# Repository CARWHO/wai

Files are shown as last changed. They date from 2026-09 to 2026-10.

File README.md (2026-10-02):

# Wai

The health monitor for your farm. It does the checking for you.

2nd at the [OpenAI Hackathon](https://saasathon.dev). Mobile app, web app and the hardware, all demoed live. [trywai.now](https://trywai.now)

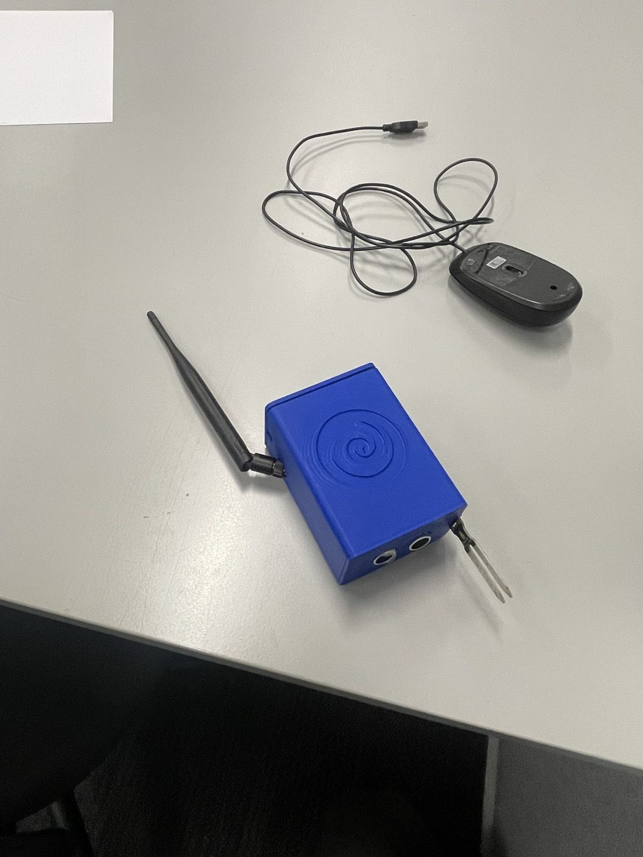
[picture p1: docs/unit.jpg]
Wai sensor unit


## Problem

- 2 h a day driving round the farm to check water and soil.
- +43% on fertiliser costs.
- $1M fine for run-off from fertilising before the rain.

## How it works

Probe → LoRa (no SIM) → gateway → cloud → AI.

Every reading lands live. The AI works out the cause, the fix and how long you've got.

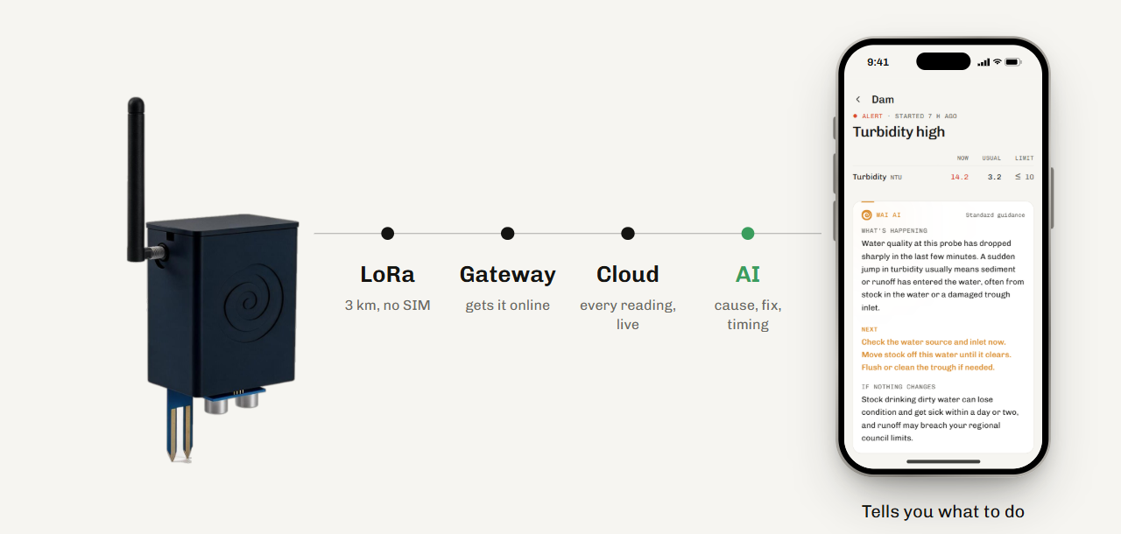
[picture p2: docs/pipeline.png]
Probe, LoRa, gateway, cloud, AI, app


## App

<p>
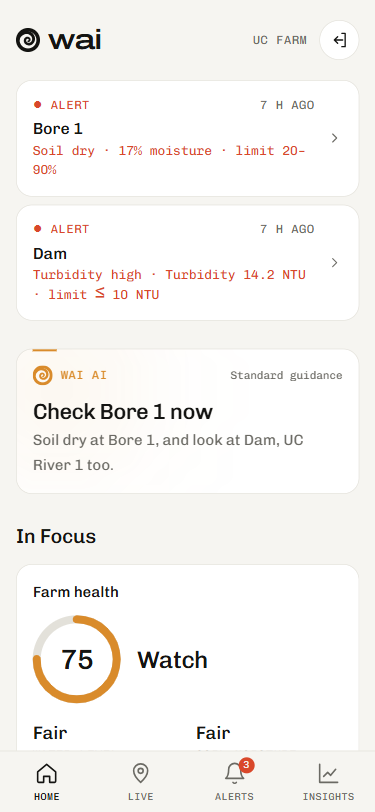
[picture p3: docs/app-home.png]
Home: alerts, Wai AI guidance and farm health score
  
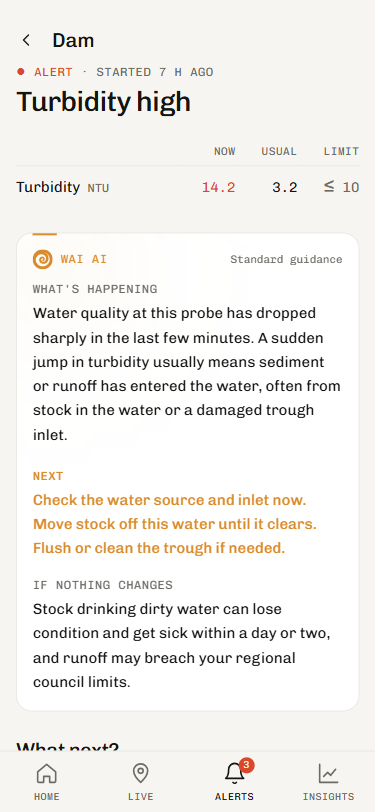
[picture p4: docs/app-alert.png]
Alert: what's happening, what to do next, what happens if nothing changes
  
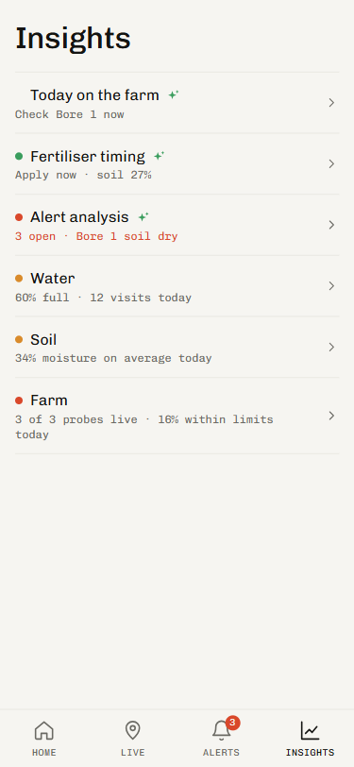
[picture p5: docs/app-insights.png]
Insights: fertiliser timing, water, soil and farm summary
  
</p>

- Farm health score
- Wai AI: suggestions and insights on each probe's current readings
- Alerts: what changed, why, what to do, what it costs if you wait
- Map of probes, with health and battery
- Live readings from the real hardware

The app is SwiftUI on Supabase. The original Next.js web app is in the git history before the `swift-primary` branch.

## Code

| Path | Contents |
|---|---|
| `Sources/WaiKit` | `Models`, `Metrics`, `Derive`, `Demo`, `Farm` (domain), `FarmStore`, `SessionStore`, `Location`, `CommandsStore`, `AIClient` |
| `Sources/WaiUI` | `Theme`, `Fonts` (Chivo, Chivo Mono, Archivo, bundled), `Components/`, `Screens/`, `Router`, `RootView` |
| `Sources/WaiiOS` | `@main` for the iOS app (Xcode project generated from `project.yml`) |
| `Sources/WaiMac` | `@main` for the macOS dev runner |
| `Sources/WaiKitCheck` | fixture checks against `Fixtures/` |
| `Sources/WaiLiveCheck` | live Supabase smoke check |
| `api/ai.ts` | Vercel function for the AI text (`https://wai-olive.vercel.app/api/ai`). The app calls it. |
| `hardware/` | firmware, wiring and enclosure |

### Open in Xcode

```sh
xcodegen generate     # only after editing project.yml; Wai.xcodeproj is committed
open Wai.xcodeproj    # scheme Wai, run on a simulator or a phone
```

Set your team under Signing before running on a phone. Location permission text is in `project.yml`.

### Without Xcode (Command Line Tools only)

```sh
swift build                          # every target, macOS
swift run WaiKitCheck                # domain checks against Fixtures/
swift run WaiLiveCheck               # loads the real farm from Supabase and prints the scores
WAI_SKIP_LOGIN=1 swift run WaiMac    # the app in a 390×844 macOS window, anonymous reads
swift run WaiMac                     # with the login screen
```

Command Line Tools ship neither XCTest nor swift-testing, so `WaiKitCheck` is an executable that exits 1 on any failure.
The fixtures were generated from the TypeScript domain code before it was retired. They are the frozen reference.

### AI function

`api/ai.ts` runs on Vercel with `OPENAI_API_KEY` (and optional `OPENAI_MODEL`) set in the project. Without a key it answers
with the rule-based fallback. Deploy with `vercel deploy` from the repo root. `vercel.json` sets no framework.

## Pricing

$99/month for the software, per device. Hardware is $0 upfront.

## Hardware

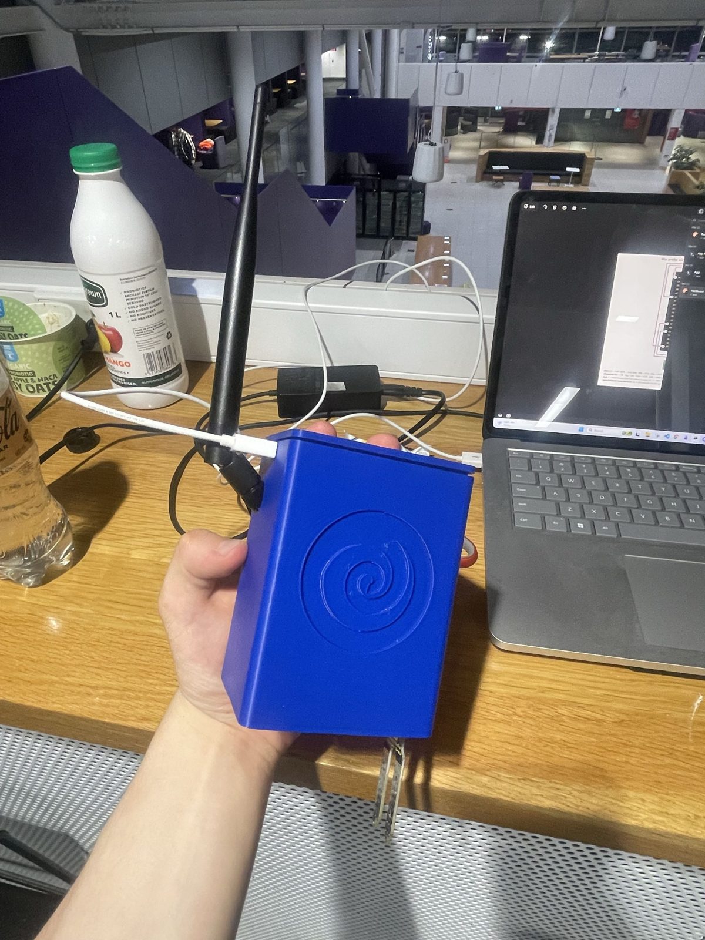
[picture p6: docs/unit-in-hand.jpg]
Holding the unit at the hackathon


Probes chain over LoRa. Each one reaches 1 to 3 km to the next, so a string of them covers a whole farm with one gateway.

- ESP32
- LoRa radio, 923 MHz
- GPS
- Ultrasonic water level sensor
- Soil moisture probe
- 3D printed case

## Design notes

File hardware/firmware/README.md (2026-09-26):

# Wai probe firmware

ESP32 (Jaycar XC3800) reads the trough water level and posts it to Supabase `readings` every 5 s. The app updates live through Realtime.

## Setup

1. Install [PlatformIO](https://platformio.org/install/cli) (`pip install platformio`) or the VS Code extension.
2. `cp include/secrets.example.h include/secrets.h` and fill in Wi-Fi, Supabase URL, publishable key and the probe id.
3. Plug the ESP32 in over USB, then `pio run -t upload && pio device monitor`.

## Modes

`SIMULATE` in `include/config.h`:

- `1`: no sensors needed. Sends a fake level that drains from 25 cm to 5 cm and refills.
- `0`: reads the real HC-SR04. Set `TANK_DEPTH_CM` to the distance from the sensor to the trough floor.

## Wiring

| Part | Pin | ESP32 |
|---|---|---|
| HC-SR04 | VCC | V5 |
| | Trig | GPIO 5 |
| | Echo | GPIO 18, through 1k/1.8k divider (1k Echo→GPIO 18, 1.8k GPIO 18→GND) |
| | GND | GND |
| Soil sensor | + | 3V3 |
| | S | GPIO 34 |
| | − | GND |
| GPS (XC3710, optional) | VCC | 3V3 |
| | GND | GND |
| | TX | GPIO 16 |
| | RX | GPIO 17 |

## Data

Each row sets `level_cm` (the only value the app uses today) and puts everything the probe read, unprocessed, into the `raw` jsonb column:

- Ultrasonic: `echo_us` (5 raw pulse widths), `echo_ok`, `distance_cm` (median)
- Soil: `soil_adc`, `soil_mv`, `soil_pct`
- Board: `uptime_s`, `rssi`, `wifi_ch`, `mac`, `free_heap`, `chip_temp_c` (die, not air), `fw`
- GPS, once a module sends valid data: `gps.{sats, fix, lat, lng, hdop, alt_m, speed_kmh, utc, age_ms, chars}`

Turn these into data points (litres, use per day, time to empty, ...) later, on the app side.

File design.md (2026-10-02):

# Design

> Superseded. This is the hackathon design note for the Next.js web app, which the `swift-primary` branch retired. The app is now the SwiftUI package at the repo root; see `README.md`. The Supabase backend, hardware and AI prompts are unchanged.

## Stack

| Layer | Choice |
|---|---|
| App | Next.js + Tailwind, installable PWA. Same tokens and fonts as the landing page (wai-web) |
| Hosting | Vercel (auto-deploy on push) |
| Backend | Supabase: Postgres, auth, Realtime |
| Hardware | ESP32 + sensors → Supabase REST over Wi-Fi |
| AI | OpenAI API via Next.js API routes |
| Emulation | Real iPhone (PWA on home screen) mirrored to Windows laptop via AeroMirror (AirPlay). Backup: Chrome DevTools device mode |
| Later | SwiftUI port on Mac, same Supabase backend |

## Libraries

| Need | Library |
|---|---|
| Framework | `next` (React 19) |
| UI | Own components in `src/components/ui.tsx`, styled with the landing page tokens (paper, ink, muted, line, healthy, alert) |
| Styling | Tailwind v4; Geist for text, JetBrains Mono for labels, units and readings |
| Backend / live data | `@supabase/supabase-js` |
| AI | `openai` (API route) |
| Map | `react-leaflet` + Esri satellite tiles (free, no key) |
| Charts | `recharts` |
| PWA | Next built-in `app/manifest.ts` |

## Data flow

ESP32 → Supabase (insert reading) → Realtime → app updates live → API route calls OpenAI → diagnosis / prediction / suggestion

## Inspiration

**Farm**
- [Halter](https://apps.apple.com/nz/app/halter/id1453448841): collars + app; virtual fences, AI health alerts
- [Farmbot](https://farmbot.com.au/): tank, bore, dam, rain monitoring; 10k+ AU producers
- [Farmdeck](https://www.farmdeck.com/features/water-level-monitoring/): real-time water levels
- [Intelli-Tank](https://apps.apple.com/us/app/intelli-tank/id1381515840): tank level + temperature app
- [Aqvify](https://aqvify.com/): well and tank level app

**Fitness (health score pattern)**
- [Oura Readiness Score](https://support.ouraring.com/hc/en-us/articles/360025589793-Readiness-Score): one 0–100 score from many signals
- [WHOOP vs Oura vs Garmin scores](https://www.kygo.app/post/recovery-scores-compared-whoop-oura-garmin): how recovery scores are built

## Demo

- **Primary**: real iPhone, app added to home screen, mirrored to Windows laptop via AeroMirror (AirPlay). Bad Wi-Fi → USB + Personal Hotspot.
- **Backup**: Chrome DevTools device mode (iPhone frame).
- **Last resort**: recorded video.

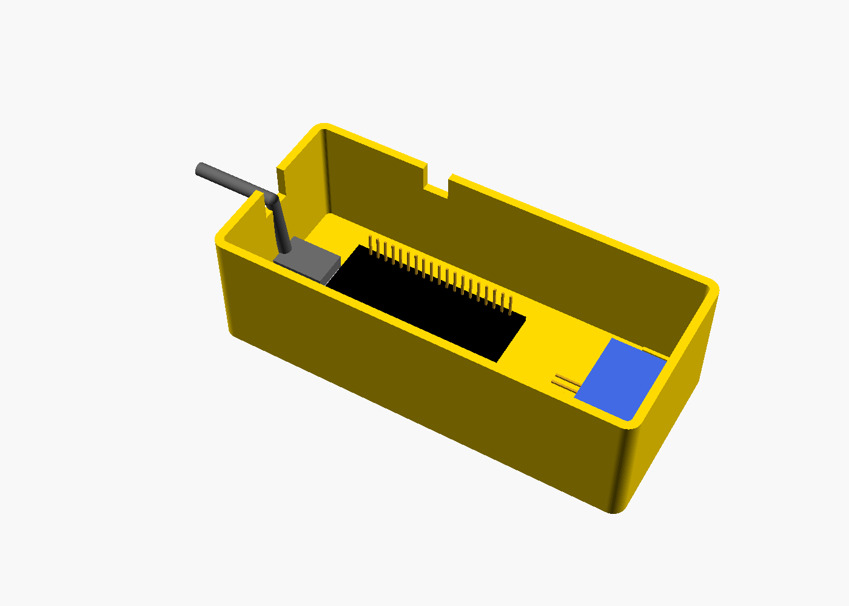
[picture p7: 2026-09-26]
hardware/enclosure/renders/inside.png

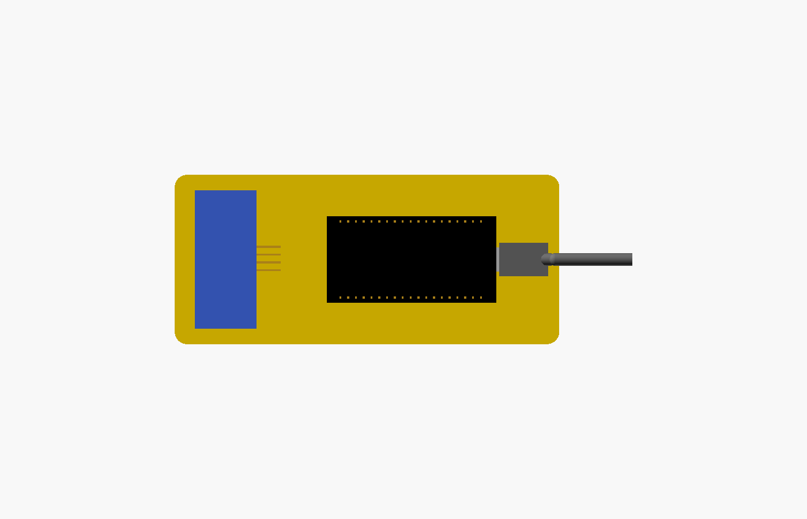
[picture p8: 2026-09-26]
hardware/enclosure/renders/top.png

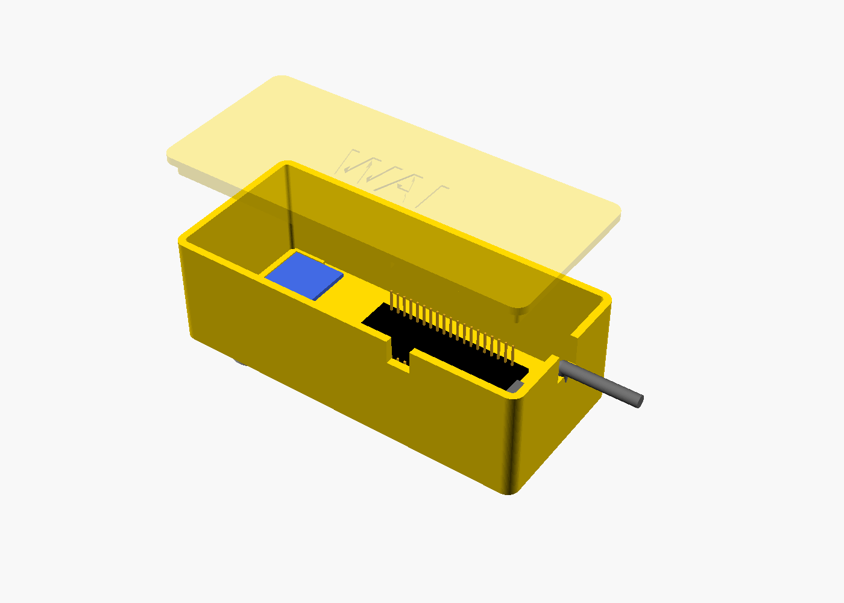
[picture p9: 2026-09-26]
hardware/enclosure/renders/with_lid.png

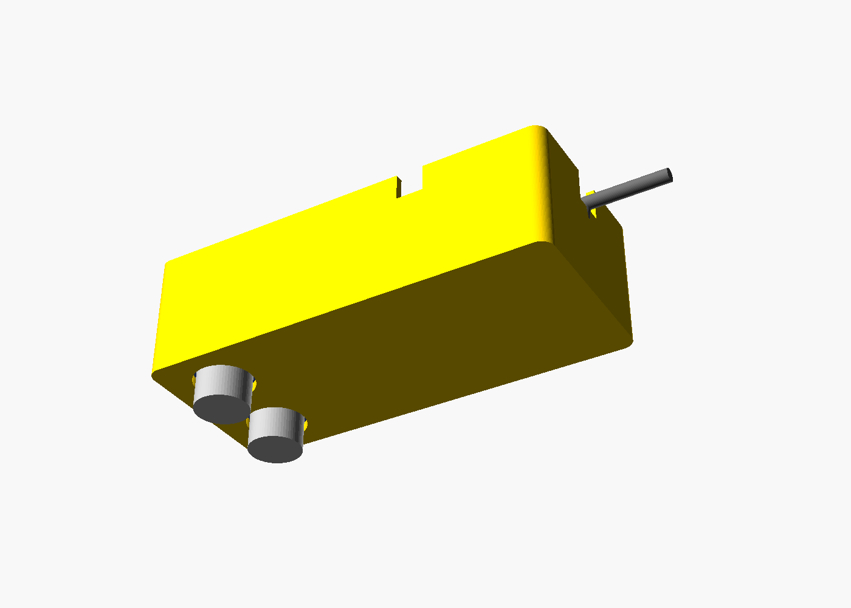
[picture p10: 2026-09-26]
hardware/enclosure/renders/underside.png

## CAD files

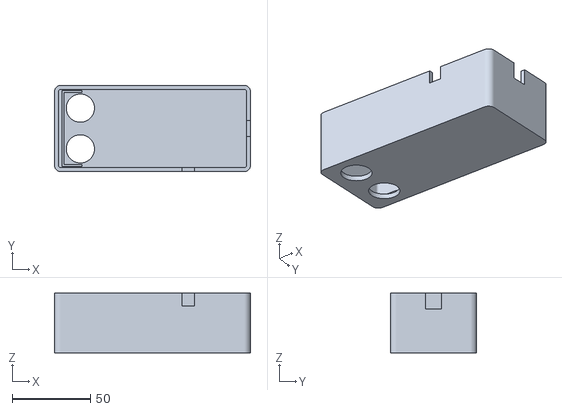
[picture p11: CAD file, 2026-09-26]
hardware/enclosure/wai_base.stl
125.0 x 55.0 x 38.0

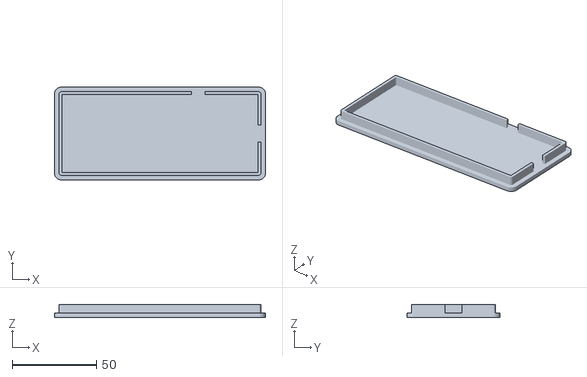
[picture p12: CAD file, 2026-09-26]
hardware/enclosure/wai_lid.stl
125.0 x 55.0 x 7.50

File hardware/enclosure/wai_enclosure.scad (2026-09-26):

// Wai demo enclosure
// Parts: ESP32 core board (Jaycar XC3800), HC-SR04 (Jaycar XC4442), optional soil sensor wires (XC4604).
// Power: USB cable from a laptop. No battery inside.
// HC-SR04 sits on the floor with its transducers pointing down through two holes, over the water.
// ESP32 is taped upside down (pins up) by its metal RF shield with double-sided tape,
// USB end facing the cable notch. The pins stick out underneath, so it can't sit flat pins-down.
// All sizes in mm. Measure your parts and adjust the variables below before printing.

part = "assembly"; // "base", "lid", "assembly", "print", "demo" (with mock parts)

/* [Interior] */
in_l = 120;  // interior length (X): HC-SR04 + its jumpers + ESP32 + micro-USB plug
in_w = 50;   // interior width (Y)
in_h = 35;   // interior height, floor top to rim

/* [Shell] */
wall  = 2.5;
floor_t = 3;
corner_r = 4;

/* [HC-SR04] */
hc_pcb_l = 45;        // PCB length (along Y)
hc_pcb_w = 20;        // PCB width (along X)
hc_tx_pitch = 26;     // centre-to-centre of the two transducers
hc_hole_d = 18;       // transducers are ~16 mm; 1 mm clearance each side
hc_rail_h = 1.5;      // low locating rails around the PCB
hc_clear = 0.5;
hc_x = 4;             // gap from the end wall to the PCB

/* [Cable exits] */
usb_notch_w = 10;     // USB cable exit, notch from the rim (micro-USB plug stays inside)
usb_notch_d = 10;
soil_notch_w = 8;     // soil sensor wires
soil_notch_d = 8;

/* [Lid] */
lid_t = 2.5;
lip_h = 5;
lip_t = 1.6;
lid_clear = 0.25;     // per side; friction fit for PLA
label = "WAI";
label_size = 14;
label_depth = 0.6;

$fn = 64;

out_l = in_l + 2 * wall;
out_w = in_w + 2 * wall;
out_h = in_h + floor_t;

module rounded_box(l, w, h, r) {
    translate([r, r, 0])
        linear_extrude(h)
            offset(r = r) square([l - 2 * r, w - 2 * r]);
}

module base() {
    difference() {
        rounded_box(out_l, out_w, out_h, corner_r);
        // cavity
        translate([wall, wall, floor_t])
            rounded_box(in_l, in_w, in_h + 1, max(corner_r - wall, 0.5));

        // HC-SR04 transducer holes, centred across the width
        hc_cx = wall + hc_x + hc_pcb_w / 2;
        for (dy = [-hc_tx_pitch / 2, hc_tx_pitch / 2])
            translate([hc_cx, out_w / 2 + dy, -1])
                cylinder(d = hc_hole_d, h = floor_t + 2);

        // USB notch in the far end wall
        translate([out_l - wall - 1, out_w / 2 - usb_notch_w / 2, out_h - usb_notch_d])
            cube([wall + 2, usb_notch_w, usb_notch_d + 1]);

        // soil sensor notch in a long wall
        translate([out_l * 0.65, -1, out_h - soil_notch_d])
            cube([soil_notch_w, wall + 2, soil_notch_d + 1]);
    }

    // locating rails for the HC-SR04 PCB; open on the pin side (+X)
    rx = wall + hc_x - hc_clear;
    ry = out_w / 2 - hc_pcb_l / 2 - hc_clear;
    rl = hc_pcb_w + 2 * hc_clear;
    rw = hc_pcb_l + 2 * hc_clear;
    translate([0, 0, floor_t]) {
        translate([rx - 1.2, ry - 1.2, 0]) cube([1.2, rw + 2.4, hc_rail_h]);
        translate([rx - 1.2, ry - 1.2, 0]) cube([rl * 0.6, 1.2, hc_rail_h]);
        translate([rx - 1.2, ry + rw, 0]) cube([rl * 0.6, 1.2, hc_rail_h]);
    }
}

module lid() {
    difference() {
        union() {
            rounded_box(out_l, out_w, lid_t, corner_r);
            // lip that drops inside the base walls
            c = lid_clear;
            ir = max(corner_r - wall - c, 0.5);
            translate([wall + c, wall + c, -lip_h])
                difference() {
                    rounded_box(in_l - 2 * c, in_w - 2 * c, lip_h, ir);
                    translate([lip_t, lip_t, -1])
                        rounded_box(in_l - 2 * c - 2 * lip_t, in_w - 2 * c - 2 * lip_t,
                                    lip_h + 2, max(ir - lip_t, 0.5));
                }
        }
        // engraved label on the top face
        translate([out_l / 2, out_w / 2, lid_t - label_depth])
            linear_extrude(label_depth + 1)
                text(label, size = label_size, halign = "center", valign = "center",
                     font = "Liberation Sans:style=Bold");
        // cut the lip where the cable notches are so the lid seats over the cables
        translate([out_l - wall - lip_t - 2, out_w / 2 - usb_notch_w / 2, -lip_h - 1])
            cube([lip_t + 4, usb_notch_w, lip_h + 1]);
        translate([out_l * 0.65, wall - 1, -lip_h - 1])
            cube([soil_notch_w, lip_t + 3, lip_h + 1]);
    }
}

// Approximate parts, only for the "demo" render. Not printed.
demo_lid = true;
esp_l = 55; esp_w = 28; esp_pcb = 1.6; esp_shield = 3.2; tape_t = 1;
module mock_parts() {
    hc_x0 = wall + hc_x;
    hc_y0 = out_w / 2 - hc_pcb_l / 2;
    // HC-SR04: PCB on the floor, transducers down through the holes, pins toward +X
    translate([hc_x0, hc_y0, floor_t]) {
        color("royalblue") cube([hc_pcb_w, hc_pcb_l, esp_pcb]);
        for (dy = [-hc_tx_pitch / 2, hc_tx_pitch / 2])
            color("silver") translate([hc_pcb_w / 2, hc_pcb_l / 2 + dy, -floor_t - 9])
                cylinder(d = 16, h = floor_t + 9);
        for (i = [0:3])
            color("goldenrod") translate([hc_pcb_w, hc_pcb_l / 2 - 3.8 + i * 2.54, 0.5])
                cube([8, 0.64, 0.64]);
    }
    // ESP32 upside down: tape, RF shield, PCB, pins up. USB end at +X.
    ex0 = out_l - wall - 18 - esp_l;   // leave ~18 mm for the micro-USB plug
    ey0 = out_w / 2 - esp_w / 2;
    translate([ex0, ey0, floor_t]) {
        color("white") translate([2, 4, 0]) cube([18, 20, tape_t]);
        color("lightgray") translate([2, 5, tape_t]) cube([18, 18, esp_shield]);
        translate([0, 0, tape_t + esp_shield]) {
            color("black") cube([esp_l, esp_w, esp_pcb]);
            for (y = [1.3, esp_w - 1.3 - 0.64])
                for (i = [0:18])
                    color("goldenrod") translate([4 + i * 2.54, y, esp_pcb]) cube([0.64, 0.64, 8]);
            color("silver") translate([esp_l - 5, esp_w / 2 - 4, -3]) cube([6, 8, 3]); // micro-USB port
        }
        // micro-USB plug and cable out through the notch
        color("dimgray") translate([esp_l + 1, esp_w / 2 - 5.5, tape_t + esp_shield - 3]) cube([16, 11, 7]);
    }
    color("dimgray")
        hull() {
            translate([out_l - wall - 2, out_w / 2, floor_t + tape_t + esp_shield]) sphere(d = 4);
            translate([out_l - wall / 2, out_w / 2, out_h - usb_notch_d + 2]) sphere(d = 4);
        }
    color("dimgray") translate([out_l - wall / 2, out_w / 2, out_h - usb_notch_d + 2])
        rotate([0, 90, 0]) cylinder(d = 4, h = 25);
}

if (part == "base") base();
else if (part == "lid") translate([0, out_w, lid_t]) rotate([180, 0, 0]) lid();
else if (part == "print") {
    base();
    translate([0, 2 * out_w + 10, lid_t]) rotate([180, 0, 0]) lid();
}
else if (part == "demo") { // mock parts for a visual check, lid lifted
    color("gold") base();
    if (demo_lid) color("gold", 0.35) translate([0, 0, out_h + 30]) lid();
    mock_parts();
}
else { // assembly, lid lifted to show the inside
    base();
    translate([0, 0, out_h + 20]) lid();
}

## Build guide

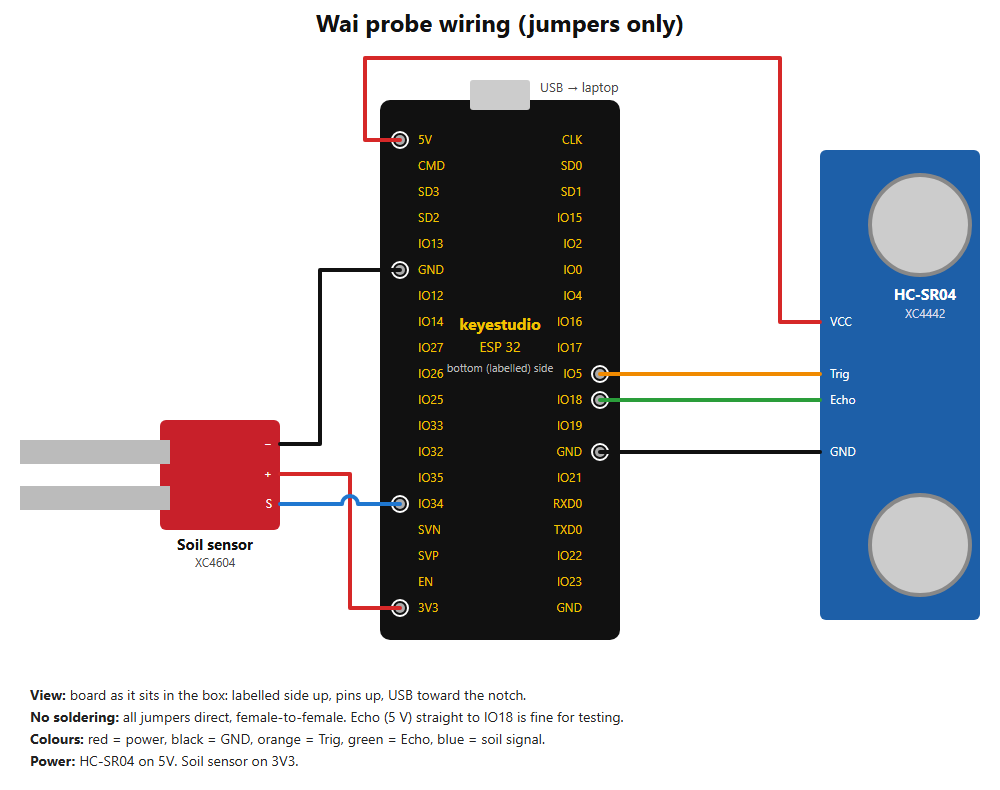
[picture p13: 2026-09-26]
hardware/wiring.png

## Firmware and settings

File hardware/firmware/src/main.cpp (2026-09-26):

// Wai probe: reads every sensor it has and inserts a row into Supabase `readings` over Wi-Fi
// every few seconds. level_cm is the one processed value the app uses today; everything else
// goes unprocessed into the `raw` jsonb column, to be turned into data points later.
// The app picks new rows up through Supabase Realtime.

#include <Arduino.h>
#include <WiFi.h>
#include <WiFiClientSecure.h>
#include <HTTPClient.h>
#include <ArduinoJson.h>
#include <TinyGPSPlus.h>
#include <algorithm>

#include "config.h"
#if __has_include("secrets.h")
#include "secrets.h"
#else
#error "Copy include/secrets.example.h to include/secrets.h and fill it in"
#endif

static TinyGPSPlus gps;

static void connectWifi() {
  if (WiFi.status() == WL_CONNECTED) return;
  Serial.printf("Wi-Fi: connecting to %s", WIFI_SSID);
  WiFi.mode(WIFI_STA);
  WiFi.begin(WIFI_SSID, WIFI_PASSWORD);
  for (int i = 0; i < 20 && WiFi.status() != WL_CONNECTED; i++) {
    delay(250);
    Serial.print('.');
  }
  if (WiFi.status() == WL_CONNECTED)
    Serial.printf(" ok, %s, RSSI %d dBm\n", WiFi.localIP().toString().c_str(), WiFi.RSSI());
  else
    Serial.println(" failed, retrying next loop");
}

// ---- HC-SR04 ----

// One ping: echo pulse width in us, 0 if no echo within ~5 m.
static unsigned long pingUs() {
  digitalWrite(PIN_TRIG, LOW);
  delayMicroseconds(2);
  digitalWrite(PIN_TRIG, HIGH);
  delayMicroseconds(20); // 10 us is the spec minimum; this board needs longer
  digitalWrite(PIN_TRIG, LOW);
  return pulseIn(PIN_ECHO, HIGH, 30000);
}

// 5 pings. Raw widths go in `raw`; the median distance (cm) is returned, NAN if none echoed.
static float readUltrasonic(JsonObject raw) {
  JsonArray pings = raw["echo_us"].to<JsonArray>();
  float v[5];
  int n = 0;
  for (int i = 0; i < 5; i++) {
    unsigned long us = pingUs();
    pings.add(us);
    if (us) v[n++] = us / 58.0f;
    delay(60); // let echoes die down
  }
  raw["echo_ok"] = n;
  if (!n) return NAN;
  std::sort(v, v + n);
  float d = v[n / 2]; // median ignores the HC-SR04's outliers
  raw["distance_cm"] = roundf(d * 10) / 10;
  return d;
}

// ---- Soil ----

static void readSoil(JsonObject raw) {
  int adc = analogRead(PIN_SOIL);
  raw["soil_adc"] = adc;
  raw["soil_mv"] = analogReadMilliVolts(PIN_SOIL);
  raw["soil_pct"] = constrain(map(adc, SOIL_DRY, SOIL_WET, 0, 100), 0, 100);
}

// ---- Board ----

static void readBoard(JsonObject raw) {
  raw["uptime_s"] = millis() / 1000;
  raw["rssi"] = WiFi.RSSI();
  raw["wifi_ch"] = WiFi.channel();
  raw["mac"] = WiFi.macAddress();
  raw["free_heap"] = ESP.getFreeHeap();
  raw["chip_temp_c"] = roundf(temperatureRead() * 10) / 10; // die temperature, not air
  raw["fw"] = FW_VERSION;
}

// ---- GPS (XC3710, optional) ----

// NMEA arrives continuously; feed the parser from loop() so no sentences are dropped.
static void feedGps() {
  while (Serial2.available()) gps.encode(Serial2.read());
}

// Adds GPS fields only once a module has sent a valid sentence (a floating RX pin reads noise),
// so rows without GPS stay clean.
static void readGps(JsonObject raw) {
  if (!gps.passedChecksum()) return;
  JsonObject g = raw["gps"].to<JsonObject>();
  g["chars"] = gps.charsProcessed();
  g["sats"] = gps.satellites.isValid() ? (int)gps.satellites.value() : 0;
  g["fix"] = gps.location.isValid() && gps.location.age() < 5000;
  if (gps.location.isValid()) {
    g["lat"] = serialized(String(gps.location.lat(), 6));
    g["lng"] = serialized(String(gps.location.lng(), 6));
    g["age_ms"] = gps.location.age();
  }
  if (gps.hdop.isValid()) g["hdop"] = gps.hdop.hdop();
  if (gps.altitude.isValid()) g["alt_m"] = gps.altitude.meters();
  if (gps.speed.isValid()) g["speed_kmh"] = gps.speed.kmph();
  if (gps.date.isValid() && gps.time.isValid()) {
    char utc[21];
    snprintf(utc, sizeof utc, "%04d-%02d-%02dT%02d:%02d:%02dZ", gps.date.year(), gps.date.month(),
             gps.date.day(), gps.time.hour(), gps.time.minute(), gps.time.second());
    g["utc"] = utc;
  }
}

// ---- Level (the one processed value the app uses) ----

static float levelCm(float distance) {
#if SIMULATE
  // Drains 1 cm per reading from 25 cm to 5 cm, then refills. Low level shows up as an alert.
  static float level = 25;
  level -= 1;
  if (level < 5) level = 25;
  return level + random(-20, 21) / 100.0f;
#else
  if (isnan(distance)) return NAN;
  return constrain(TANK_DEPTH_CM - distance, 0.0f, TANK_DEPTH_CM);
#endif
}

static bool send(JsonDocument &doc) {
  WiFiClientSecure tls;
  tls.setInsecure(); // demo only: skips certificate checks
  HTTPClient http;
  http.begin(tls, String(SUPABASE_URL) + "/rest/v1/readings");
  http.addHeader("apikey", SUPABASE_KEY);
  http.addHeader("Content-Type", "application/json");
  http.addHeader("Prefer", "return=minimal");

  String body;
  serializeJson(doc, body);
  int code = http.POST(body);
  if (code != 201) Serial.printf("Supabase: HTTP %d %s\n", code, http.getString().c_str());
  http.end();
  return code == 201;
}

void setup() {
  Serial.begin(115200);
  pinMode(PIN_TRIG, OUTPUT);
  pinMode(PIN_ECHO, INPUT);
  pinMode(PIN_LED, OUTPUT);
  analogReadResolution(12);
  Serial2.setRxBufferSize(4096); // holds NMEA while we ping and post
  Serial2.begin(GPS_BAUD, SERIAL_8N1, PIN_GPS_RX, PIN_GPS_TX);
  Serial.printf("\nWai probe %s, fw %s, %s mode\n", PROBE_ID, FW_VERSION, SIMULATE ? "SIMULATE" : "sensor");
  connectWifi();
}

void loop() {
  feedGps();
  static unsigned long last = 0;
  if (last && millis() - last < SEND_INTERVAL_S * 1000UL) return;
  last = millis();

  connectWifi();

  JsonDocument doc;
  doc["probe_id"] = PROBE_ID;
  JsonObject raw = doc["raw"].to<JsonObject>();
  float distance = readUltrasonic(raw);
  readSoil(raw);
  readBoard(raw);
  readGps(raw);
  float level = levelCm(distance);
  if (!isnan(level)) doc["level_cm"] = roundf(level * 10) / 10;
  if (SIMULATE) raw["simulated"] = true;

  serializeJson(doc, Serial);
  Serial.println();

  if (WiFi.status() == WL_CONNECTED && send(doc)) {
    digitalWrite(PIN_LED, HIGH); // blink on every successful send
    delay(100);
    digitalWrite(PIN_LED, LOW);
  }
}

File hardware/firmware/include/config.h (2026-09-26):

#pragma once

// 1 = no sensors attached: sends a fake trough level that drains and refills.
// 0 = read the real HC-SR04 and soil sensor.
#define SIMULATE 0

// Pins
#define PIN_TRIG 5    // HC-SR04 Trig
#define PIN_ECHO 18   // HC-SR04 Echo, through a 1k/1.8k divider (5 V -> 3.3 V)
#define PIN_SOIL 34   // soil sensor S pin; ADC1 only, ADC2 doesn't work with Wi-Fi on
#define PIN_LED 2     // onboard LED on most ESP32 core boards
#define PIN_GPS_RX 16 // ESP32 RX <- GPS TX (XC3710, optional)
#define PIN_GPS_TX 17 // ESP32 TX -> GPS RX
#define GPS_BAUD 9600

#define FW_VERSION "0.2.0"

// Sensor to trough floor, in cm. Water level = this minus the measured distance.
#define TANK_DEPTH_CM 30.0f

// Soil sensor calibration: raw ADC in dry air and in a glass of water.
#define SOIL_DRY 0      // XC4604 reads 0 in air
#define SOIL_WET 1500   // and ~1300-1500 in a cup of water

// Seconds between readings. Short for the demo.
#define SEND_INTERVAL_S 5

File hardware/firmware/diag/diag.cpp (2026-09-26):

// HC-SR04 diagnostic: Trig IO5, Echo IO18. Prints hit rate per 10 pings.
#include <Arduino.h>

void setup() {
  Serial.begin(115200);
  pinMode(5, OUTPUT);
  pinMode(18, INPUT);
  digitalWrite(5, LOW);
}

void loop() {
  int hits = 0;
  String s;
  for (int i = 0; i < 10; i++) {
    digitalWrite(5, HIGH); delayMicroseconds(20); digitalWrite(5, LOW);
    unsigned long us = pulseIn(18, HIGH, 60000);
    if (us) hits++;
    s += String(us / 58.0, 1) + " ";
    delay(70);
  }
  Serial.printf("hits %d/10: %s| soil ADC %d\n", hits, s.c_str(), analogRead(34));
}

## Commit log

2026-09-25 docs: libraries, switch to Astryx
2026-09-26 feat: Wai prototype app, firmware and enclosure
    Next.js app (Home, Live map, Probe, Alerts, Insights, Report) styled after
    Halter and Garmin Connect, reading probe data from Supabase. ESP32 firmware
    and enclosure files for the probe.
    [wai_base.stl, wai_enclosure.scad, wai_lid.stl]
2026-09-26 feat: probe sends all raw sensor values, app handles level-only readings
    - Firmware posts every raw reading (ultrasonic echoes, soil, board stats,
    optional XC3710 GPS) into the new readings.raw jsonb column
    - Fix HC-SR04 missing echoes with a 20 us trigger pulse; calibrate soil
    - Add HC-SR04 diagnostic env (pio run -e diag)
    - App: turbidity/pH/TDS may be null; score, breaches and report skip them
    - Allow hotspot LAN origin for the dev server
    [config.h, diag.cpp, main.cpp]
2026-09-26 fix: Vercel build without env vars; show live probe at phone location
    - Fall back to the public Supabase URL and publishable key when
    NEXT_PUBLIC_* env vars are missing (build failed with "supabaseUrl is required")
    - Watch the phone's position and draw the ESP32 probe (rows with raw data)
    there; map jumps to it on first fix
2026-09-26 feat: restyle app to match the landing page; place probe by its GPS fix
    Same design tokens and fonts as wai-web: paper background, ink text,
    white cards with hairline borders, Geist for text and JetBrains Mono for
    labels, units and readings. Round ink buttons and chips, medium weight
    headings. Alert cards follow the landing page phone mock. Drops Astryx,
    which nothing used and which tinted titles olive.
    The hardware probe is now drawn at its own GPS fix when the reading has
    one, else next to the phone, else where the probes table says.
2026-09-26 perf: smooth map zoom and open the Live tab instantly
    - Re-enable Leaflet zoom, fade and marker animations. With them off, Leaflet
    dropped every tile at each zoom step and the map went blank until the new
    tiles arrived. Fetch tiles at zoom end only and keep a larger tile buffer.
    - Keep one Leaflet map for the whole app session (LiveMapProvider). It mounts
    as soon as the probes load and stays full-size but invisible off the Live
    tab, so the first tap on Live shows a map with tiles already loaded.
    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
2026-09-26 feat: run the app on real sensor data with AI alerts, fertiliser timing and geofence
    Level, % full and soil moisture replace turbidity/pH/TDS where absent.
    Alerts for low level, dry/saturated soil, probe moved (GPS geofence) and
    probe offline, each with AI diagnosis and a rule-based fallback. Insights
    gets trough visits and an AI fertiliser-timing card using the Open-Meteo
    forecast. Device tab adds LoRa controls and 'set home' for the geofence.
2026-09-26 feat: sign in with Supabase auth; sensor check on the Live probe sheet
2026-09-26 feat: Insights as a drill-down list; drop Probes/Alerts buttons from Live
2026-09-26 feat: Insights opens Water, Soil and Farm as their own lists; plain sensor check labels
2026-09-26 feat: demo mode keeps the hardware probe looking live; rename account to UC farm
2026-09-26 style: Geist Mono and balanced text wrapping, as on the landing page
2026-09-26 fix: demo mode ignores poor GPS fixes and places the probe at the phone
2026-09-26 feat: demo mode alerts on the seeded probes and a past low-water event on UC River 1
2026-09-26 feat: demo mode shows real sensor values and only fakes the GPS fix
2026-09-26 feat: AI alerts name the cause, the fix and the cost by when; gpt-5 at minimal reasoning
    The probe is the test: the prompt bans testing kits, labs and monitoring lines.
    Alerts send the trend since they started, the probe position and the past 48 h
    of rain, and the page shows the risk with its deadline. Impossible readings are
    called out as a sensor fault. The Home tip uses the same rules.
2026-09-26 feat: Chivo, Chivo Mono and the Archivo wordmark, as on the landing page
2026-09-29 ios: router, app shell, login gate, screen stubs, SensorCheck and FarmTip
2026-09-29 ios: Login, Home, Alerts, Alert detail, Probe, Live map, Insights, Report screens; TrendChart, AlertList, FarmMap, ProbeControls
2026-09-29 ios: skip-login switch on the iOS entry; simulator build verified on Xcode 27
2026-10-01 docs: pitch slides as PDF
2026-10-02 Swift is the primary app: package at the repo root, Next.js web app removed
    Move the Swift package from ios/ to the root and regenerate Wai.xcodeproj
    there. Remove the Next.js app, its configs and the fixture generator. The
    web app stays in history before this commit.
    Keep the AI route as a standalone Vercel function at api/ai.ts, with a
    minimal package.json and vercel.json (no framework). The iOS app keeps
    calling it at the same URL.
    Fixtures/ is now the frozen reference for WaiKitCheck. Drop the web file
    paths from Swift comments, merge the iOS README into README.md, replace
    the Next.js AGENTS.md, and mark design.md as superseded.
    swift build and swift run WaiKitCheck (133,428 checks) p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
